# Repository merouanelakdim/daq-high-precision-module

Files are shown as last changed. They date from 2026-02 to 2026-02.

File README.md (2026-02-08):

🌟 High‑Precision Data Acquisition Module (DAQ)







A compact and robust 4‑channel data acquisition module designed with a strong focus on signal integrity, low noise, and clean analog/digital separation.
Built around an STM32 microcontroller, an analog multiplexer, and carefully tuned RC filtering, this board is engineered for reliable and accurate measurements.

🚀 Features
4 multiplexed analog input channels

STM32 microcontroller for fast sampling and processing

Optimized RC filter (R4/C9) for ADC input stabilization

Clean analog/digital domain separation

UART interface for communication

SWD interface for programming and debugging

2‑layer PCB designed with KiCad

Low‑noise power architecture with ferrite bead isolation

🧩 Hardware Architecture
Analog Front-End

4 input channels

Multiplexer for channel selection

RC low‑pass filter to stabilize ADC readings

Digital Core

STM32 MCU

SPI communication

UART interface

SWD programming header

Power Section

5V input

3.3V regulation

Analog/digital power separation

Decoupling and filtering for noise reduction

📁 Repository Structure
Code
📦 daq-high-precision-module
 ┣ 📂 hardware/        → KiCad project files (schematic + PCB)
 ┗ 📜 README.md        → You are here
🖼️ PCB Preview



🎯 Project Goals
Build a compact and reliable DAQ module

Ensure clean analog signal acquisition

Apply professional PCB design practices

Optimize routing for low noise and stability

Provide a reusable hardware platform for future projects

🛠️ Tools & Technologies
KiCad 8 for schematic and PCB design

STM32 ecosystem

LTspice for analog simulation

Git & GitHub for version control

👤 Author
Merouane Lakdim  
Embedded Electronics Engineer — Paris, France
Passionate about hardware design, signal integrity, and embedded systems.

📄 License
This project is licensed under the **MIT License**. See the [LICENSE](LICENSE) file for details.

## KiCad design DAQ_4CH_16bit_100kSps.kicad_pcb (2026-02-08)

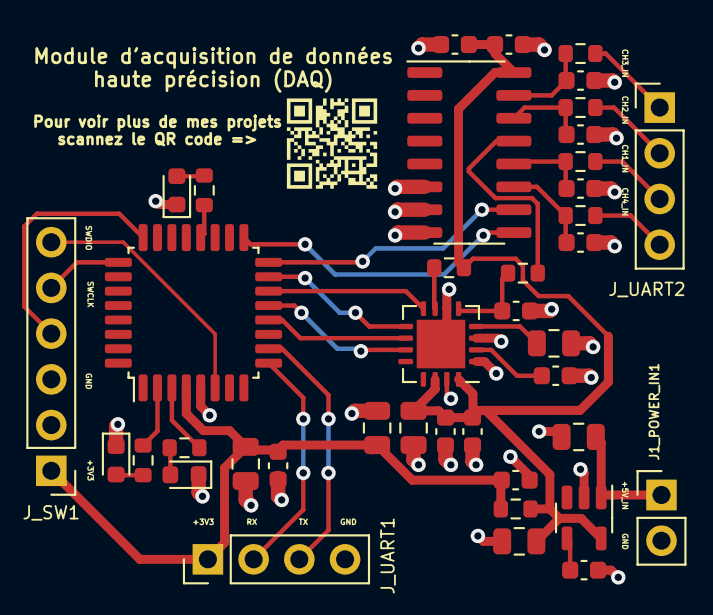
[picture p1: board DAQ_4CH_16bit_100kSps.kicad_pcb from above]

Board: 2 copper layers, 40 parts (0 on the bottom side), 35 nets.

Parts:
C0, C6, C7: 4.7 µF; C_0805_2012Metric
C1, C2, C3, C4, C8, C10, C11, C12, C13, C14: 100 nF; C_0603_1608Metric
C5: 10 µF; C_0805_2012Metric
C9: 220 pF; C_0603_1608Metric
CBYP1: 10 nF; C_0603_1608Metric
CIN1: 1 µF; C_0805_2012Metric
COUT1: 10 µF; C_0805_2012Metric
Cdec1: 100 nF; C_0603_1608Metric
D1, D2, D3: LED; LED_0603_1608Metric
FB1: FerriteBead; R_0603_1608Metric
J1_POWER_IN1: Conn_01x02; PinHeader_1x02_P2.54mm_Vertical
J_SW1: Conn_01x06; PinHeader_1x06_P2.54mm_Vertical
J_UART1, J_UART2: Conn_01x04; PinHeader_1x04_P2.54mm_Vertical
R1, R2, R3, R6, R7, R8, R9: 1 kΩ; R_0603_1608Metric
R4: 33 Ω; R_0603_1608Metric
R5: 10 kΩ; R_0603_1608Metric
U1: LT1763‑3.3; SOT-23-5
U2: STM32G0B1KBTx; LQFP-32_7x7mm_P0.8mm
U3: ADS8681RUM; QFN-16-1EP_4x4mm_P0.65mm_EP2.7x2.7mm
U5: CD4052B; SOIC-16_3.9x9.9mm_P1.27mm

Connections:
+3V3_ANA: C2.1, C7.1, C8.2, C10.1, COUT1.1, Cdec1.2, FB1.1, R5.2, U1.5 (OUT), U3.14 (DVDD), U3.16 (AVDD), U5.16 (VDD)
+3V3_DIG: C0.1, C1.2, C4.1, C5.1, FB1.2, J_SW1.1, J_UART1.1, U2.4 (VDD)
+5V_IN: CIN1.1, J1_POWER_IN1.1, U1.1 (IN)
CH1_FILT: C11.2, R6.2, U5.12 (X0)
CH1_IN: J_UART2.3, R6.1
CH2_FILT: C12.2, R7.2, U5.14 (X1)
CH2_IN: J_UART2.2, R7.1
CH3_FILT: C13.2, R8.2, U5.15 (X2)
CH3_IN: J_UART2.1, R8.1
CH4_FILT: C14.2, R9.2, U5.11 (X3)
CH4_IN: J_UART2.4, R9.1
GND: C0.2, C1.1, C2.2, C3.2, C4.2, C5.2, C6.1, C7.2, C8.1, C9.1, C10.2, C11.1, C12.1, C13.1, C14.1, CBYP1.2, CIN1.2, COUT1.2, Cdec1.1, D1.1 (K), D2.1 (K), D3.1 (K), J1_POWER_IN1.2, J_SW1.3, J_UART1.4, U1.2 (GND), U2.5 (VSS), U3.1 (AGND), U3.3 (REFGND), U3.6 (AIN_GND), U3.15 (DGND), U3.17 (PAD), U5.6 (INH), U5.7 (VEE), U5.8 (VSS)
MUX_OUT: R4.1, U5.13 (X)
MUX_S0: U2.16 (PB1), U5.10 (A)
MUX_S1: U2.17 (PB2), U5.9 (B)
unnamed: D1.2 (A), R1.1
unnamed: D2.2 (A), R2.1
unnamed: D3.2 (A), R3.1
unnamed: J_SW1.4, U2.24 (PA13)
unnamed: J_SW1.5, U2.25 (PA14)
unnamed: J_SW1.6, U2.6 (PF2)
unnamed: J_UART1.2, U2.9 (PA2)
unnamed: J_UART1.3, U2.10 (PA3)
unnamed: CBYP1.1, U1.4 (BP)
unnamed: R1.2, U2.20 (PC6)
unnamed: R2.2, U2.2 (PC14)
unnamed: R3.2, U2.3 (PC15)
unnamed: C9.2, R4.2, U3.5 (AIN_P)
unnamed: C6.2, U3.4 (REFCAP)
unnamed: C3.1, U3.2 (REFIO)
unnamed: R5.1, U3.7 (~RST)
SPI_CS_ADC: U2.15 (PB0), U3.9 (CONVST/~CS)
SPI_MISO: U2.13 (PA6), U3.11 (SDO-0)
SPI_MOSI: U2.14 (PA7), U3.8 (SDI)
SPI_SCK: U2.12 (PA5), U3.10 (SCLK)

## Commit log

2026-02-08 Initial commit – DAQ high precision PCB
    [ADC_MUX.kicad_sch, ANALOG_CH.kicad_sch, DAQ_4CH_16bit_100kSps.kicad_pcb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]
2026-02-08 Update README with license details and remove image
    Removed outdated PCB image and updated license information.
2026-02-08 Add PCB preview image and project goals section
    Added a second PCB preview image and updated project goals.

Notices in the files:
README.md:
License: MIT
